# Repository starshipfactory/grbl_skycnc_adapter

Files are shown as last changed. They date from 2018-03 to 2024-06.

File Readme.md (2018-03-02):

# GRBL SKYCNC Adapter

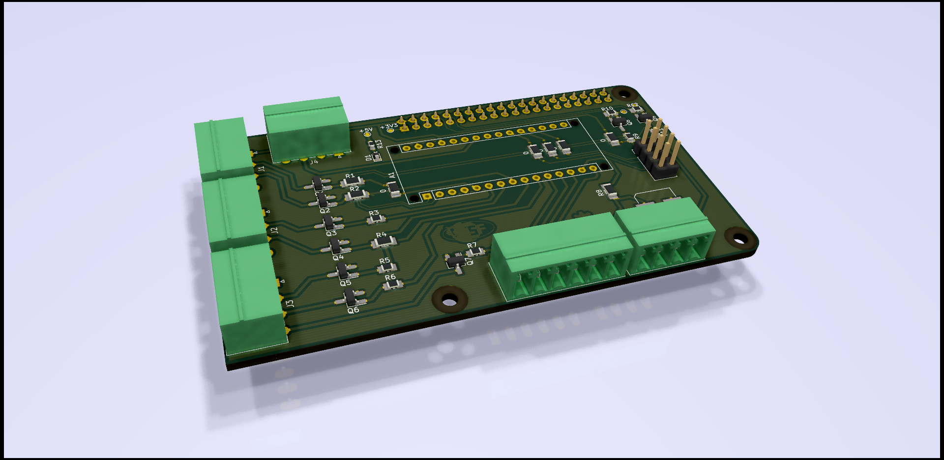
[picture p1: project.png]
GRBL SKYCNC Adapter


Für unsere Skycnc Maschine wollen wir einen neue Zeitgemässe Steuerungseinheit implementieren. Hier kann die Arduino basierte Steuerungssoftware grbl eingesetzt werden.

Für die nutzung von grbl mit der aktuell vorhandenen hardware sind folgende Schnittstellen auf einem interfaceboard zu designen:

- [x] Interface zu Schrittmotortreibern, Lieferung 5V und GND für Ansteuerung Optokoppler
- [x] Interface zu Tastkopf für Werkzeuglänge und Werkstückdetektion (GND -> Maschine, Sense -> Werkzeug)
- [x] Interface zu Spindelsteuerung mit Freigabe und 0-10V Drehzahlsteuerung
- [x] Interface zu bestehenden Endschaltern / Austausch der Endschalter
- [ ] Ersatz der Hardwareschalter durch neue
- [x] Vorbereitung für Anschluss Reset/Abort, FeedHold, CycleStart/Resume
- [ ] Einbau zusätzlicher Taster für Reset/Abort, FeedHold, CycleStart/Resume

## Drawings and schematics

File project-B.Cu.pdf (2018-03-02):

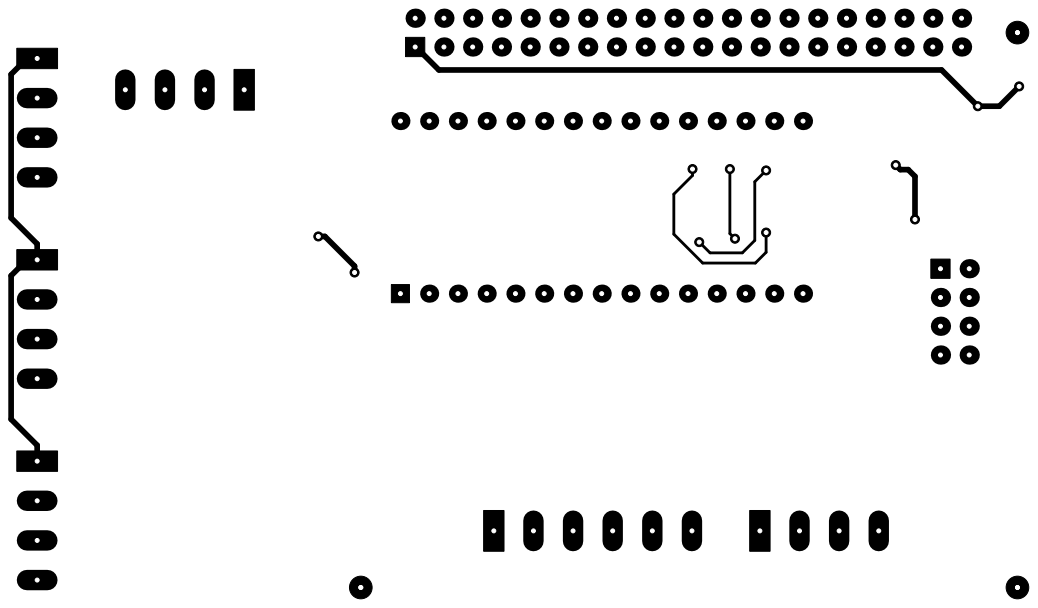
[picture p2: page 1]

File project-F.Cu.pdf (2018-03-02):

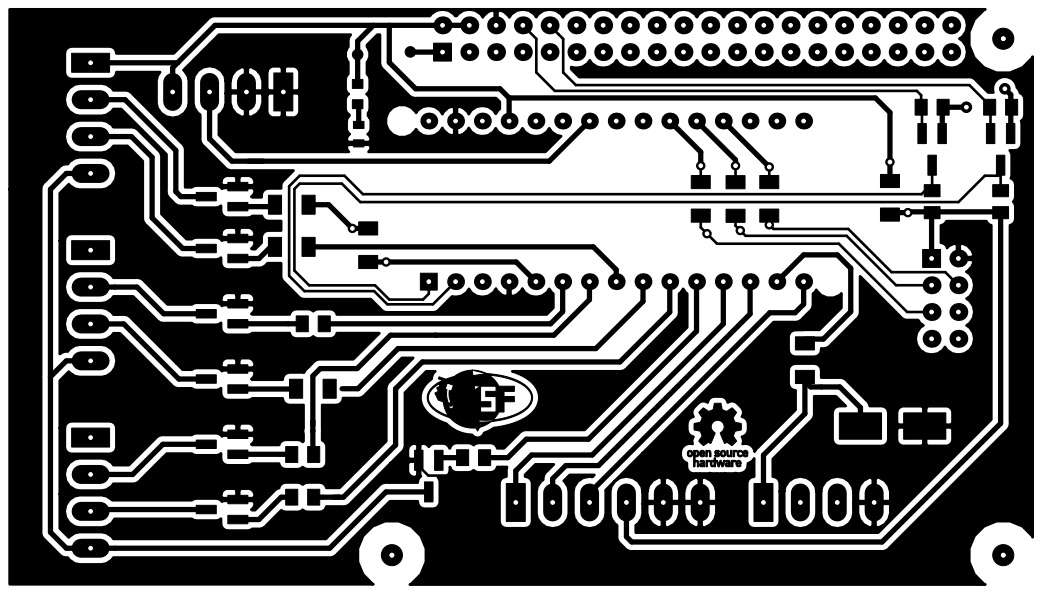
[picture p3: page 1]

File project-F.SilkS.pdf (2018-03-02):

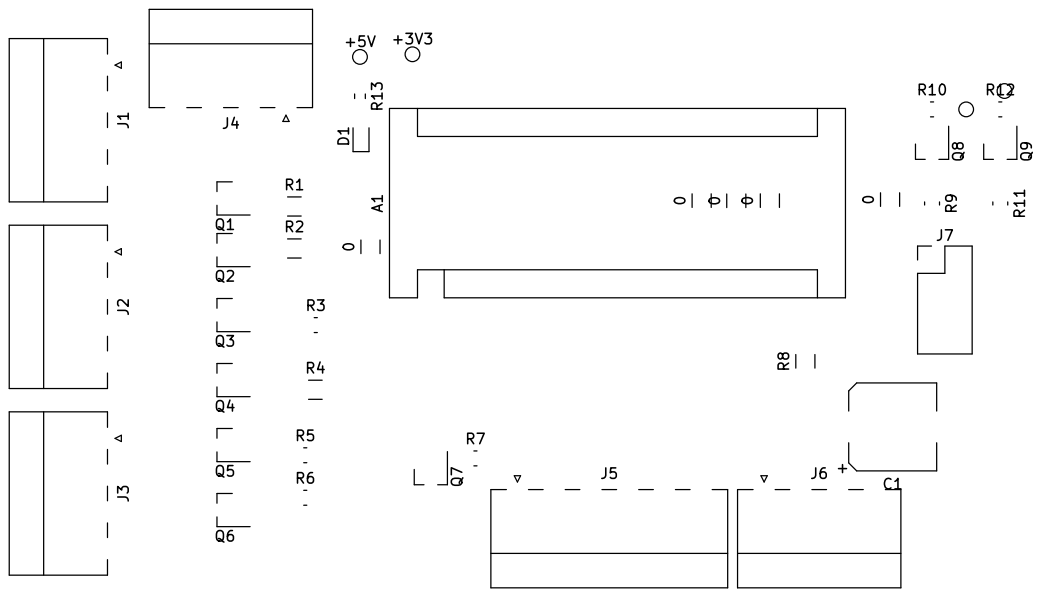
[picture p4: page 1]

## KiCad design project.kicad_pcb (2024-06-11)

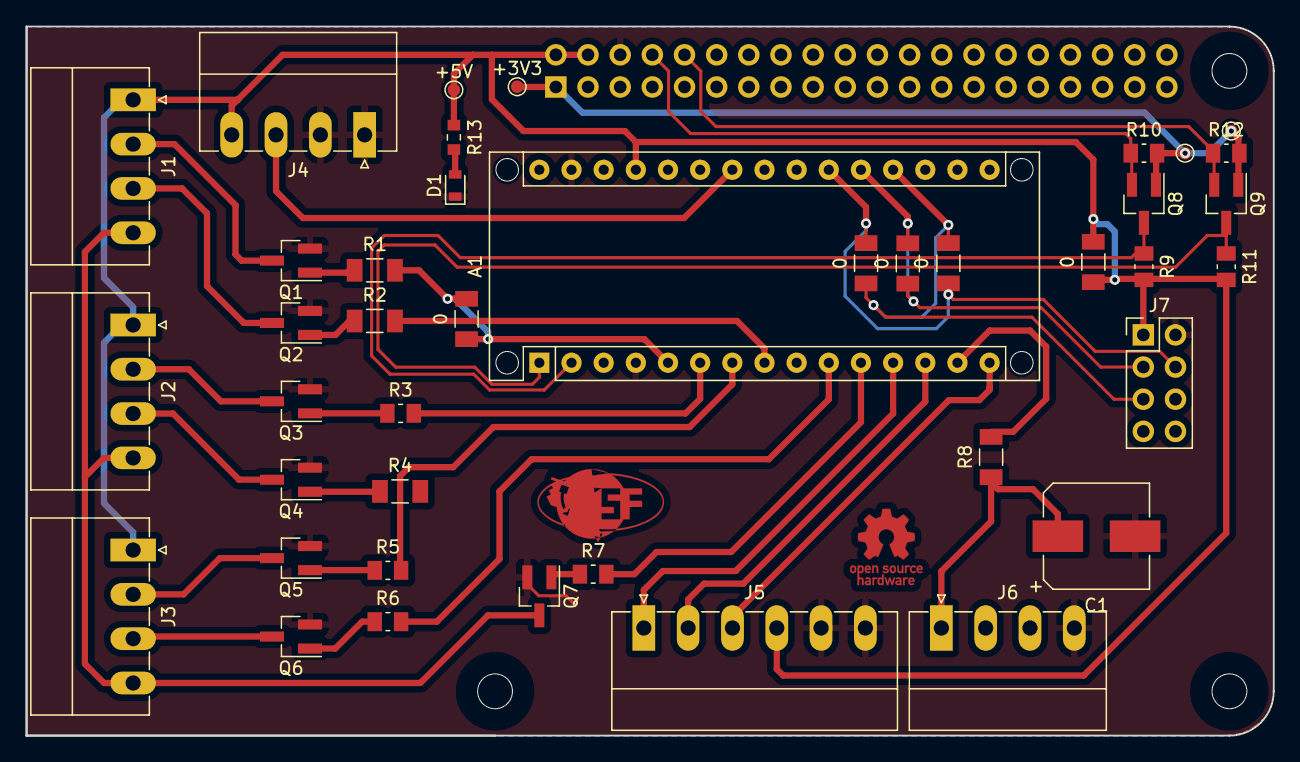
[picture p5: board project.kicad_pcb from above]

Board: 2 copper layers, 98.5 x 56.0 mm, 43 parts (1 on the bottom side), 40 nets.

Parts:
0, 0#2, 0#3, 0#4, 0#5: 0; R_1206_3216Metric_Pad1.24x1.80mm_HandSolder
+3V3, +3V3#2: TestPoint_Pad_D1.0mm
+3V3#3: +3V3; TestPoint_Pad_D1.0mm
+5V: +5V; TestPoint_Pad_D1.0mm
A1: Arduino_Nano_v3.x; Arduino_Nano_WithMountingHoles
C1: 1uF; CP_Elec_8x10
D1: LED; D_0603_1608Metric_Pad0.67x1.00mm_HandSolder
J1, J2, J3, J4, J6: Conn_01x04; PhoenixContact_MC_1,5_4-G-3.5_1x04_P3.50mm_Horizontal
J5: Conn_01x06; PhoenixContact_MC_1,5_6-G-3.5_1x06_P3.50mm_Horizontal
J7: Conn_01x04; PinHeader_2x04_P2.54mm_Vertical
J9: Conn_02x20_Odd_Even; pi-gpio
Q1, Q2, Q3, Q4, Q5, Q6, Q7: BC848; SOT-23_Handsoldering
Q8, Q9: 2N7002; SOT-23_Handsoldering
R1, R2, R4: 10k; R_1206_3216Metric_Pad1.24x1.80mm_HandSolder
R3, R5, R6, R7, R9, R10, R11, R12: 10k; R_0805_2012Metric_Pad1.15x1.50mm_HandSolder
R8: 47k; R_1206_3216Metric_Pad1.24x1.80mm_HandSolder
R13: 220; R_0603_1608Metric_Pad0.84x1.00mm_HandSolder
Ref**: Val**; sf_logo

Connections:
+3V3: +3V3.1, +3V3#2.1, +3V3#3.1, J9.1, Q8.1 (G), Q9.1 (G), R10.2, R12.2
+5V: 0#2.1, 0#2.2, +5V.1, A1.27 (+5V), J1.1, J2.1, J3.1, J4.4, J5.4, J7.1, J9.2, J9.4, R9.2, R11.2, R13.1
/Stell_DZ: C1.1, J6.1, R8.1
CycleStart/Resume: 0#3.2, 0#5.1
CycleStart/Resume: A1.21 (A2), J7.4
DirX: A1.8 (D5), R2.2
DirXOut: J1.3, Q2.3 (C)
DirY: A1.9 (D6), R4.2
DirYOut: J2.3, Q4.3 (C)
DirZ: A1.10 (D7), R6.2
DirZOut: J3.3, Q6.3 (C)
Earth: A1.4 (GND), A1.29 (GND), C1.2, D1.1 (K), J4.1, J4.2, J5.5, J5.6, J6.4, J7.2, J9.6, Q1.2 (E), Q2.2 (E), Q3.2 (E), Q4.2 (E), Q5.2 (E), Q6.2 (E), Q7.2 (E)
FeedHold: 0#4.1, 0#4.2, A1.20 (A1), J7.3
LimitX: A1.12 (D9), J5.1
LimitY: A1.13 (D10), J5.2
LimitZ: A1.15 (D12), J5.3
unnamed: D1.2 (A), R13.2
unnamed: Q1.1 (B), R1.1
unnamed: Q2.1 (B), R2.1
unnamed: Q3.1 (B), R3.1
unnamed: Q4.1 (B), R4.1
unnamed: Q5.1 (B), R5.1
unnamed: Q6.1 (B), R6.1
unnamed: Q7.1 (B), R7.1
Probe: A1.24 (A5), J4.3
RXD: J9.10, Q9.2 (S), R12.1
RX_5V: A1.2 (D0/RX), Q8.3 (D), R9.1
Reset/Abort: 0#3.1, 0#5.2
Reset/Abort: A1.19 (A0), J7.5
SpindlePWM: A1.14 (D11), R8.2
StepX: 0.1, 0.2, A1.5 (D2), R1.2
StepXOut: J1.2, Q1.3 (C)
StepY: A1.6 (D3), R3.2
StepYOut: J2.2, Q3.3 (C)
StepZ: A1.7 (D4), R5.2
StepZOut: J3.2, Q5.3 (C)
StepperEN: A1.11 (D8), R7.2
StepperENOut: J1.4, J2.4, J3.4, Q7.3 (C)
TXD: J9.8, Q8.2 (S), R10.1
TX_5V: A1.1 (D1/TX), Q9.3 (D), R11.1

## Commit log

2017-12-08 Initiaier Commit
    [project.kicad_pcb, project.sch]
2017-12-08 Some improvements
    [project.kicad_pcb]
2018-02-23 Diverse Anpassung, umstellug uf SMD
    [project.kicad_pcb, project.sch]
2018-02-27 Fertiggestelltes Layout
    [project.kicad_pcb, project.sch]
2018-03-02 Update auf vorhandene Bauteile & Korrektur 3D Objekte
    [project.kicad_pcb, project.sch]
2018-03-02 Neuerzeugen der Plots zum Ätzen
    [project.kicad_pcb]
2024-06-11 Generated new Gerber files & new Kicad version
    [project.kicad_pcb, project.kicad_sch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]
2024-06-11 Fixed wrong Layer on Gerbers
    [project.kicad_pcb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]
2024-06-11 Gerber 0 Positions are appreciated
    [project.kicad_pcb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]
2024-06-11 Set 0 for Gerbers for real this time
    [project-Edge_Cuts.gbr, project-F_Cu.gbr, project-F_Mask.gbr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]
